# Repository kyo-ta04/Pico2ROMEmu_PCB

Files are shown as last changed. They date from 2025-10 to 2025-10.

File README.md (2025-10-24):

# Pico2ROMEmu\_PCB
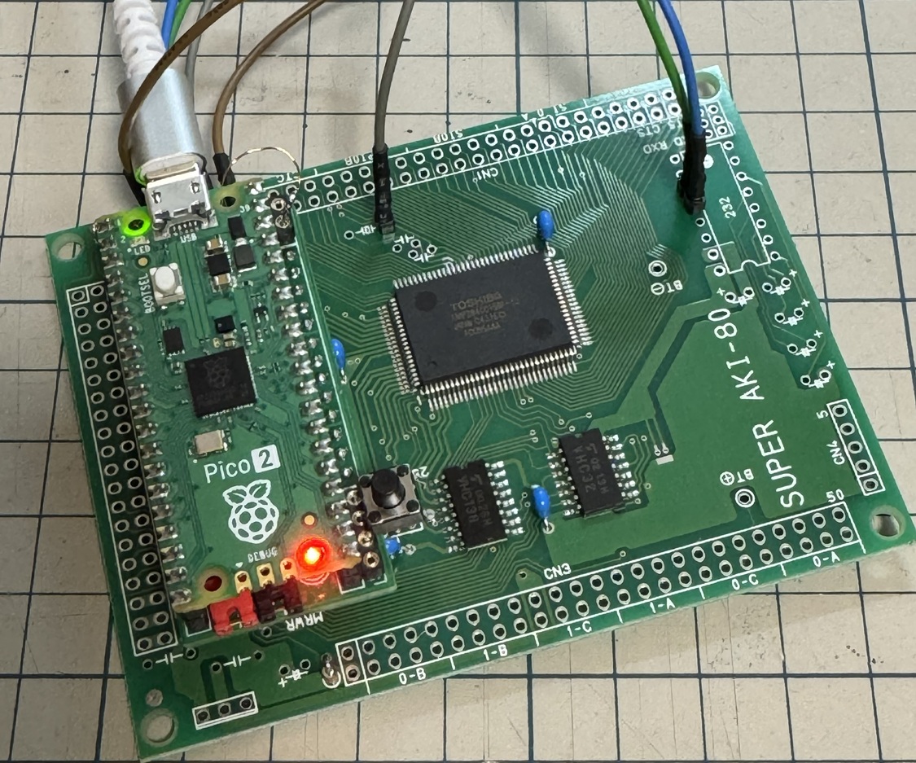
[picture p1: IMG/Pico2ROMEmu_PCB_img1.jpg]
Pico2ROMEmu_PCB img


Pico2ROMEmu PCB
This is a KiCad project for a Pico2ROMEmu ROM emulator.  
For more information, please see [Pico2ROMEmu](https://github.com/kyo-ta04/Pico2ROMEmuBR).  
- KiCad Version: 9.0.5  
- License: MIT  
- Includes: Schematic, PCB layout, BOM, Gerber files  

KiCanvas view ->
[schematics](https://kicanvas.org/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), 
[board](https://kicanvas.org/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)  

Gerber file -> [Pico2ROMEmu_PCB_0.1.zip](https://github.com/kyo-ta04/Pico2ROMEmu_PCB/blob/master/production/Pico2ROMEmu_PCB_0.1.zip)

## Schematics and Documents
- Assembly instructions (note.com)
  - [Pico2ROMEmuの組み立て方](https://note.com/quiet_duck4046/n/n425d6b7e8d55?sub_rt=share_sb)
  - [Super AKI-80の組み立て方(最少部品編)](https://note.com/quiet_duck4046/n/n32906e1dfb96?sub_rt=share_sb)  
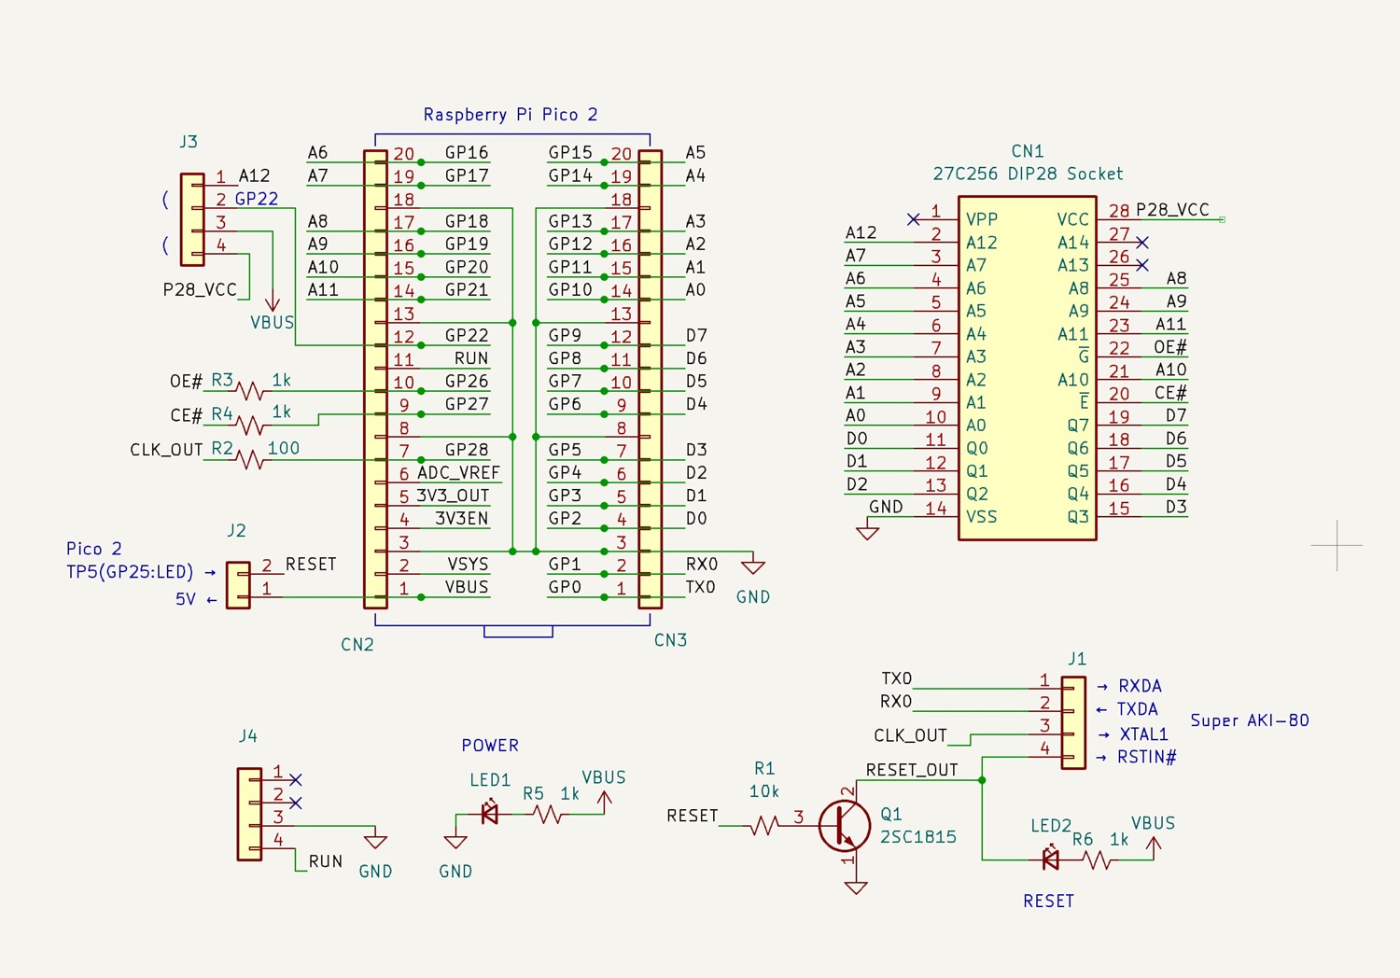
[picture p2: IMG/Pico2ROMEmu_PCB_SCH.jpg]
Pico2ROMEmu_PCB sch
- 
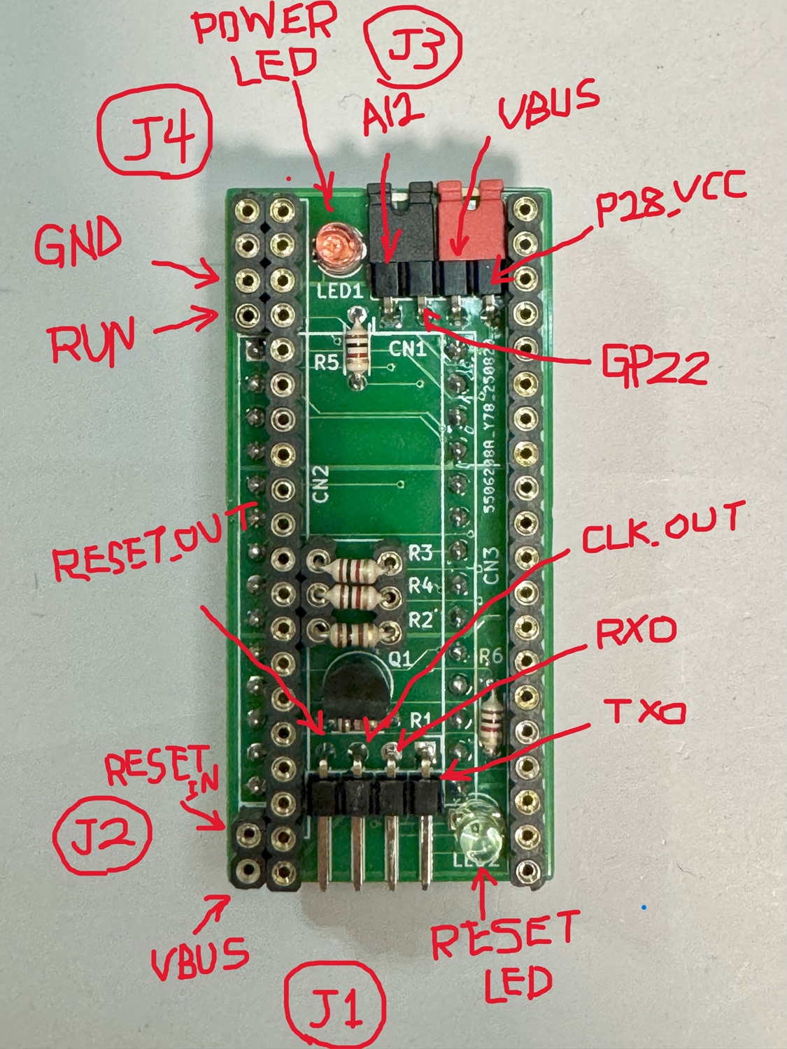
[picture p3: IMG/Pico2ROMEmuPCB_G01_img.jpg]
Pico2ROMEmu_PCB img2
- 

## Disclaimer
This software is provided as is. The author is not responsible for any damage.

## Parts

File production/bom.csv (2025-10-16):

Designator | Footprint | Quantity | Value | LCSC Part #
CN1 | DIP-28_W15.24mm_Socket | 1 | 27C256 DIP28 Socket
CN2, CN3 | PinSocket_1x20_P2.54mm_Vertical | 2 | Conn_01x20
J1, J3 | PinHeader_1x04_P2.54mm_Horizontal | 2 | Conn_01x04
J2 | PinHeader_1x02_P2.54mm_Vertical | 1 | Conn_01x02
J4 | PinHeader_1x04_P2.54mm_Vertical | 1 | Conn_01x04
LED1 | LED_D3.0mm | 1 | LED_Small
LED2 | LED_D3.0mm_Clear | 1 | LED_Small
Q1 | TO-92_Inline | 1 | 2SC1815
R1 | R_Axial_DIN0204_L3.6mm_D1.6mm_P5.08mm_Horizontal | 1 | 10k
R2 | R_Axial_DIN0204_L3.6mm_D1.6mm_P5.08mm_Horizontal | 1 | 100
R3, R4, R5, R6 | R_Axial_DIN0204_L3.6mm_D1.6mm_P5.08mm_Horizontal | 4 | 1k

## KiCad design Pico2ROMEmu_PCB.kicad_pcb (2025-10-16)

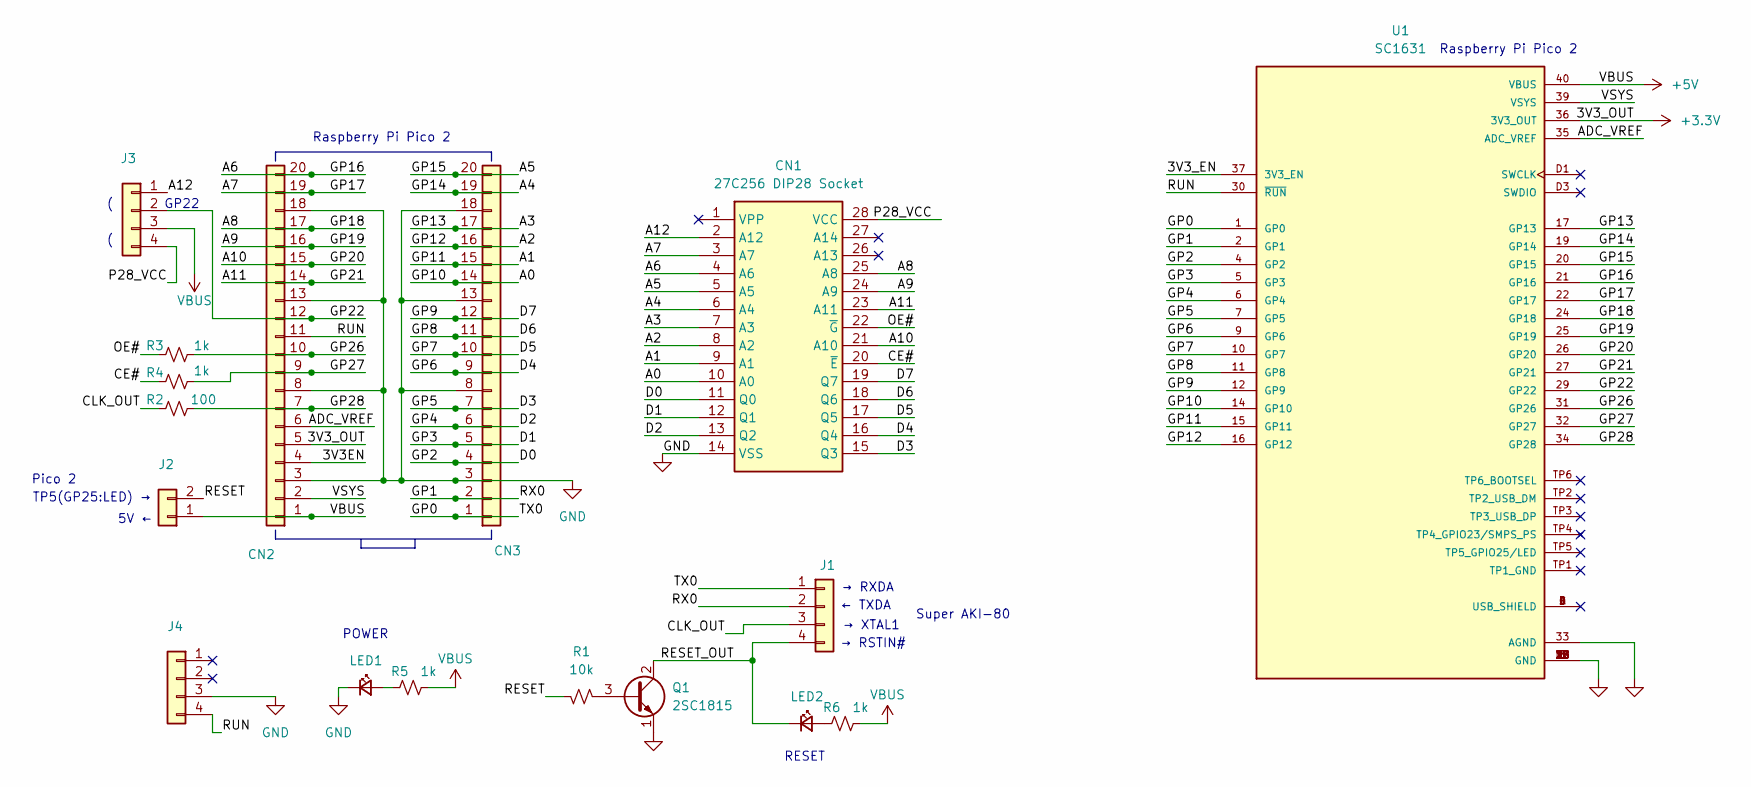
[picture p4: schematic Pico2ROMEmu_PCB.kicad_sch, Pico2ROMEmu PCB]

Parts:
CN1: 27C256 DIP28 Socket; DIP-28_W15.24mm_Socket; Manufacturer_Part_Number M27C256B-15F1; Mouser Part Number 511-M27C256B-15F
CN2, CN3: Conn_01x20; PinSocket_1x20_P2.54mm_Vertical
J1, J3: Conn_01x04; PinHeader_1x04_P2.54mm_Horizontal
J2: Conn_01x02; PinHeader_1x02_P2.54mm_Vertical
J4: Conn_01x04; PinHeader_1x04_P2.54mm_Vertical
LED1: LED_Small; LED_D3.0mm
LED2: LED_Small; LED_D3.0mm_Clear
Q1: 2SC1815; TO-92_Inline
R1: 10k; R_Axial_DIN0204_L3.6mm_D1.6mm_P5.08mm_Horizontal
R2: 100; R_Axial_DIN0204_L3.6mm_D1.6mm_P5.08mm_Horizontal
R3, R4, R5, R6: 1k; R_Axial_DIN0204_L3.6mm_D1.6mm_P5.08mm_Horizontal
U1: SC1631; MODULE_SC0915; PARTREV 1.9

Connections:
+3.3V: CN2.5, U1.36 (3V3_OUT)
+5V: CN2.1, J2.1, J3.3, R5.1, R6.1, U1.40 (VBUS)
/3V3EN: CN2.4
/A0: CN1.10 (A0), CN3.14, U1.14 (GP10)
/A1: CN1.9 (A1), CN3.15, U1.15 (GP11)
/A2: CN1.8 (A2), CN3.16, U1.16 (GP12)
/A3: CN1.7 (A3), CN3.17, U1.17 (GP13)
/A4: CN1.6 (A4), CN3.19, U1.19 (GP14)
/A5: CN1.5 (A5), CN3.20, U1.20 (GP15)
/A6: CN1.4 (A6), CN2.20, U1.21 (GP16)
/A7: CN1.3 (A7), CN2.19, U1.22 (GP17)
/A8: CN1.25 (A8), CN2.17, U1.24 (GP18)
/A9: CN1.24 (A9), CN2.16, U1.25 (GP19)
/A10: CN1.21 (A10), CN2.15, U1.26 (GP20)
/A11: CN1.23 (A11), CN2.14, U1.27 (GP21)
/A12: CN1.2 (A12), J3.1
/ADC_VREF: CN2.6, U1.35 (ADC_VREF)
/CE#: CN1.20 (~E), R4.2
/CLK_OUT: J1.3, R2.2
/D0: CN1.11 (Q0), CN3.4, U1.4 (GP2)
/D1: CN1.12 (Q1), CN3.5, U1.5 (GP3)
/D2: CN1.13 (Q2), CN3.6, U1.6 (GP4)
/D3: CN1.15 (Q3), CN3.7, U1.7 (GP5)
/D4: CN1.16 (Q4), CN3.9, U1.9 (GP6)
/D5: CN1.17 (Q5), CN3.10, U1.10 (GP7)
/D6: CN1.18 (Q6), CN3.11, U1.11 (GP8)
/D7: CN1.19 (Q7), CN3.12, U1.12 (GP9)
/GP0: CN3.1, J1.1, U1.1 (GP0)
/GP1: CN3.2, J1.2, U1.2 (GP1)
/GP22: CN2.12, J3.2, U1.29 (GP22)
/GP26: CN2.10, R3.1, U1.31 (GP26)
/GP27: CN2.9, R4.1, U1.32 (GP27)
/GP28: CN2.7, R2.1, U1.34 (GP28)
/OE#: CN1.22 (~G), R3.2
/P28_VCC: CN1.28 (VCC), J3.4
/RESET: J2.2, R1.1
/RESET_OUT: J1.4, LED2.1 (K), Q1.2 (C)
/RUN: CN2.11, J4.4, U1.30 (~RUN)
/VSYS: CN2.2, U1.39 (VSYS)
GND: CN1.14 (VSS), CN2.3, CN2.8, CN2.13, CN2.18, CN3.3, CN3.8, CN3.13, CN3.18, J4.3, LED1.1 (K), Q1.1 (E), U1.3 (GND), U1.8 (GND), U1.13 (GND), U1.18 (GND), U1.23 (GND), U1.28 (GND), U1.33 (AGND), U1.38 (GND), U1.D2 (GND)
unnamed: LED1.2 (A), R5.2
unnamed: LED2.2 (A), R6.2
unnamed: Q1.3 (B), R1.2
unnamed: U1.A (USB_SHIELD), U1.B (USB_SHIELD), U1.C (USB_SHIELD), U1.D (USB_SHIELD)

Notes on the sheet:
← TXDA
→ RXDA
RESET
TP5(GP25:LED) →
→ XTAL1
Pico 2
POWER
5V ←
Super AKI-80
GP22
Raspberry Pi Pico 2
→ RSTIN#

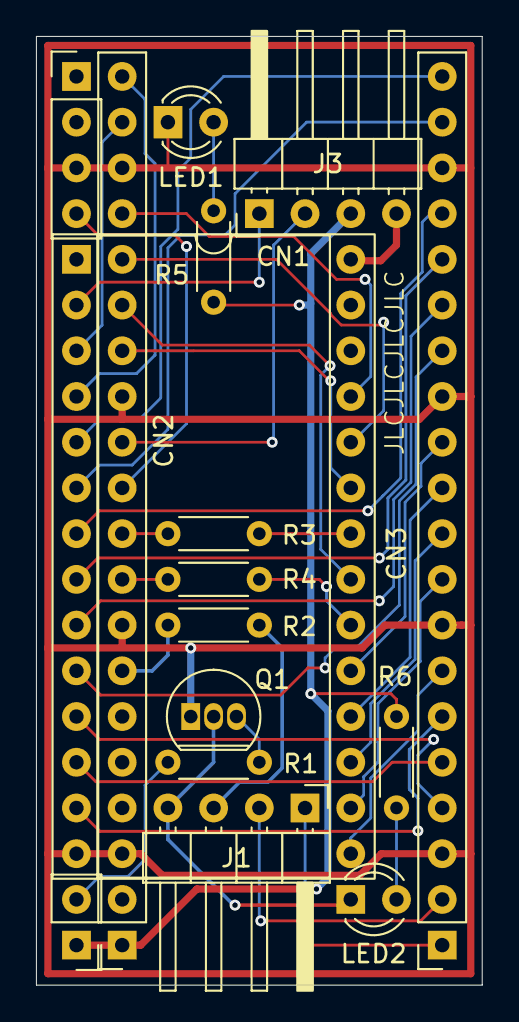
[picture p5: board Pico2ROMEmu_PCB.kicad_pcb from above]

Board: 2 copper layers, 24.8 x 52.7 mm, 16 parts (0 on the bottom side), 39 nets.
